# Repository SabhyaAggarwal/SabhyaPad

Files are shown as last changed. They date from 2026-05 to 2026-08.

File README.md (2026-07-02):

# SabhyaPad

This is my own MacroPad, called **SabhyaPad**! It has 6 buttons that can easily be customized using QMK. Using it is really simple: just plug a USB-C cable into your computer, allow it to connect, and then start using it.



I made this so that my life is easier. Currently, it is configured to do this...



## Here is a [video](https://youtu.be/60F119tDTQQ) of it on YouTube!!! I accidentally put the wrong link in the demo section actually...

## BOM
|Item |Quantity|Remarks |Unit Price 1 (INR)|Order Quantity|Order Unit Price (INR)|Order Unit Price (Est. USD)|Link To Buy |
|---|---|---|---|---|---|---|---|
|Switches |6 |Switches of MX style. |₹93.18 |6 |₹93.18 |$1.00 |https://www.mouser.in/ProductDetail/CHERRY/MX1A-L1NN?qs=F5EMLAvA7IDlALNAurZTXA%3D%3D |
|Seeed Studio Xiao RP2040|1 |Main Chip. |₹464.97 |1 |₹464.97 |$4.90 |https://www.mouser.in/ProductDetail/Seeed-Studio/102010630?qs=sqEgtWRSLJ0HHL%252BkmwiGyA%3D%3D |
|Blank DSA keycaps |6 |Blank DSA keycaps of black colour(3d printed).|₹2.13 |6 |₹12.75 |$0.13 |Own 3d printer or print-legion |
|PCB |1 |Main PCB. |₹1112.00 |1 |₹95.25 |$1.00 |allpcb.com |
|M3x16mm screws |4 |Screws. |₹12.27 |4 |₹49.09 |$0.51 |https://robokits.co.in/robot-parts/nut-bolts-standoffs/mushroom-head-bolts/m3-x-16-mm-ss-bolt-precision-stainless-steel-304-moq-25-pcs|
|M3 nuts |4 |Nuts |₹1.18 |4 |₹4.72 |$0.05 |https://robokits.co.in/robot-parts/nut-bolts-standoffs/nuts/m3-nuts-304-stainless-steel-moq-50-pcs |

## Hardware

This is the schematic of my PCB...



And this is what my PCB design looks like...



### 3D Render of PCB



## 3D Models

Please note that I will add USB-C port after I receive the PCB and can confirm the measurements

### Case Render(SabhyaPad Case Assembled)

Screenshot 2026-06-10 at 11 30 27 PM

### Cut Case Render(SabhyaPad Case Cut)

Screenshot 2026-06-10 at 11 31 21 PM

### Final Render(no keycaps)

Screenshot 2026-06-10 at 11 29 30 PM

---

# Assembly

For assembly:
1. 3D Print the case cut file.
2. Take your soldered PCB and push it into the top part. It will click and then it will be attached.
3. Take the bottom part and put it at the bottom.
4. Use M3x16mm screws and the M3 nuts to enclose it.

# Firmware

The SabhyaPad firmware is based on **QMK Firmware** and is located in:

```text
FIRMWARE/sabhyapad
```

## Requirements

Install **QMK MSYS** from:

https://qmk.fm

After installation, open QMK MSYS and verify it is installed correctly:

```bash
qmk --version
```

## Setting Up QMK

Clone and set up QMK Firmware:

```bash
qmk setup
```

## Installing SabhyaPad

Navigate to the keyboards directory:

```bash
cd qmk_firmware/keyboards
```

Clone this repository:

```bash
git clone https://github.com/SabhyaAggarwal/SabhyaPad.git
```

## Building the Firmware

Return to the QMK root directory:

```bash
cd ../..
```

Compile the firmware:

```bash
qmk compile -kb sabhyapad -km default
```

Or:

```bash
make sabhyapad:default
```

## Firmware Output

A successful build will generate:

```text
sabhyapad_default.uf2
```

Since SabhyaPad uses an **RP2040** microcontroller, the firmware is generated in UF2 format.

## Flashing the Firmware

1. Hold the **BOOTSEL** button while plugging the keyboard into your computer.
2. A drive named **RPI-RP2** will appear.
3. Drag and drop:

```text
sabhyapad_default.uf2
```

onto the drive.

The keyboard will automatically reboot and start running the new firmware.

## Updating

Pull the latest changes:

```bash
cd qmk_firmware/keyboards/SabhyaPad
git pull
```

Rebuild:

```bash
cd ../..
qmk compile -kb sabhyapad -km default
```

## Troubleshooting

Check your QMK installation:

```bash
qmk doctor
```

Clean and rebuild:

```bash
qmk clean
qmk compile -kb sabhyapad -km default
```

List available keymaps:

```bash
qmk list-keymaps -kb sabhyapad
```

## Quick Start

```bash
qmk setup

cd qmk_firmware/keyboards
git clone https://github.com/SabhyaAggarwal/SabhyaPad.git

cd ../..

qmk compile -kb sabhyapad -km default
```

### Specifications

- MCU: RP2040
- Switches: 6 Mechanical Switches
- Firmware: QMK
- Connector: USB-C
- Firmware Format: UF2

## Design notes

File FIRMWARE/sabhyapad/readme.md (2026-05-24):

# sabhyapad

sabhyapad

*A short description of the keyboard/project*

* Keyboard Maintainer: [Sabhya Aggarwal](https://github.com/SabhyaAggarwal)
* Hardware Supported: *The PCBs, controllers supported*
* Hardware Availability: *Links to where you can find this hardware*

Make example for this keyboard (after setting up your build environment):

    make sabhyapad:default

Flashing example for this keyboard:

    make sabhyapad:default:flash

See the [build environment setup](https://docs.qmk.fm/#/getting_started_build_tools) and the [make instructions](https://docs.qmk.fm/#/getting_started_make_guide) for more information. Brand new to QMK? Start with our [Complete Newbs Guide](https://docs.qmk.fm/#/newbs).

## Bootloader

Enter the bootloader in 3 ways:

* **Bootmagic reset**: Hold down the key at (0,0) in the matrix (usually the top left key or Escape) and plug in the keyboard
* **Physical reset button**: Briefly press the button on the back of the PCB - some may have pads you must short instead
* **Keycode in layout**: Press the key mapped to `QK_BOOT` if it is available

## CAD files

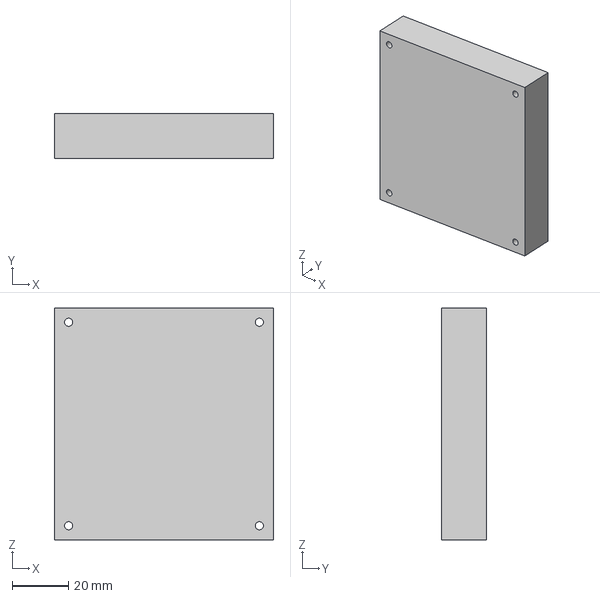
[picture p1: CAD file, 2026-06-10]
CAD/SabhyaPad Case Assembled.step
77.8 x 16.0 x 82.2 mm

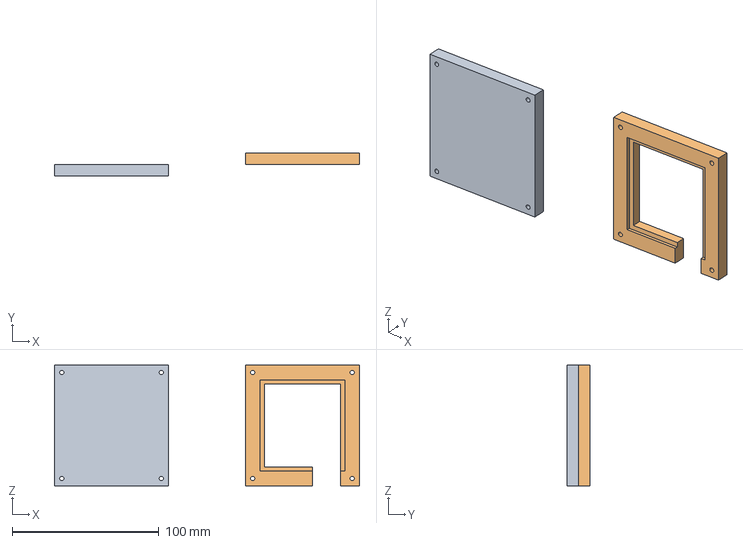
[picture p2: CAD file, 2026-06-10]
CAD/SabhyaPad Case Cut.step
207.8 x 16.0 x 82.2 mm

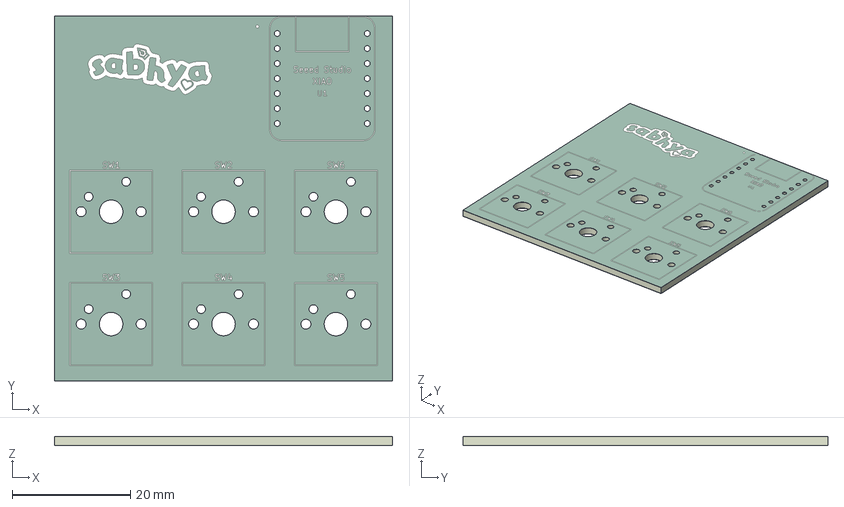
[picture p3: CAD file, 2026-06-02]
PCB/pcb.step
57.3 x 61.8 x 1.64 mm
SabhyaPad_silkscreen
SabhyaPad_soldermask x 2
SabhyaPad_PCB

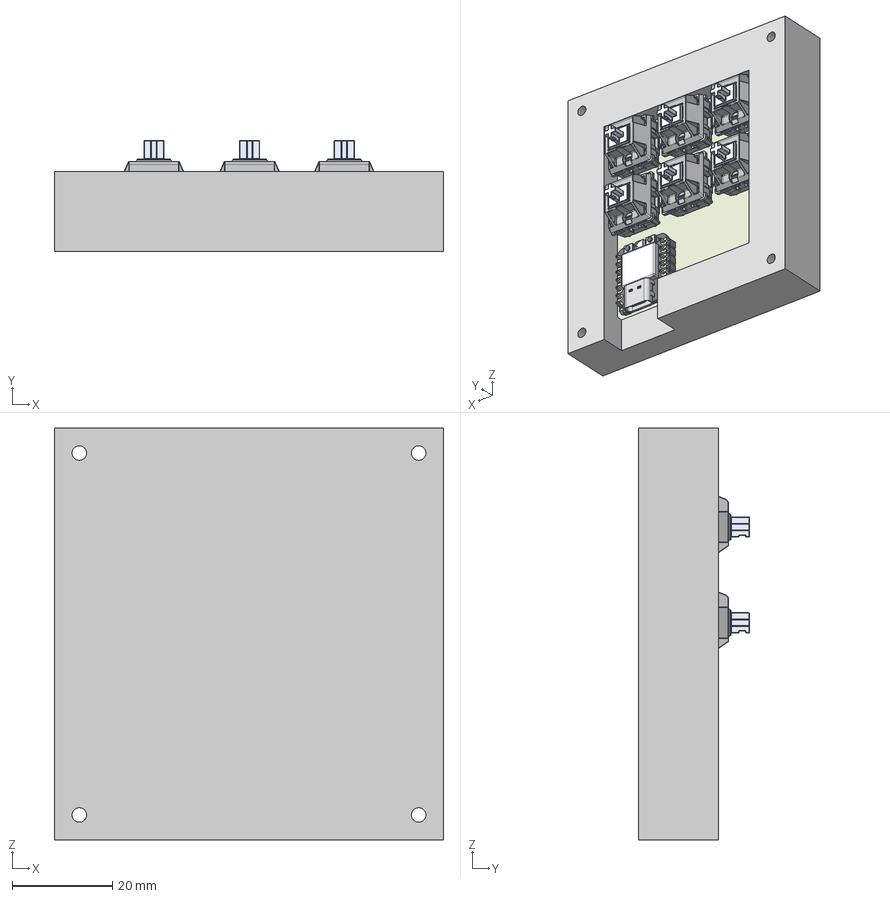
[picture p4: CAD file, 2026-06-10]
CAD/SabhyaPad Case with Components and PCB.step
77.8 x 22.2 x 82.2 mm

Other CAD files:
PRODUCTION/SabhyaPad Case Cut.stl
CAD/SabhyaPad Case Assembled.f3d
CAD/SabhyaPad Case Cut.f3d
CAD/SabhyaPad Case with Components and PCB.f3d
PCB/pcb.stl

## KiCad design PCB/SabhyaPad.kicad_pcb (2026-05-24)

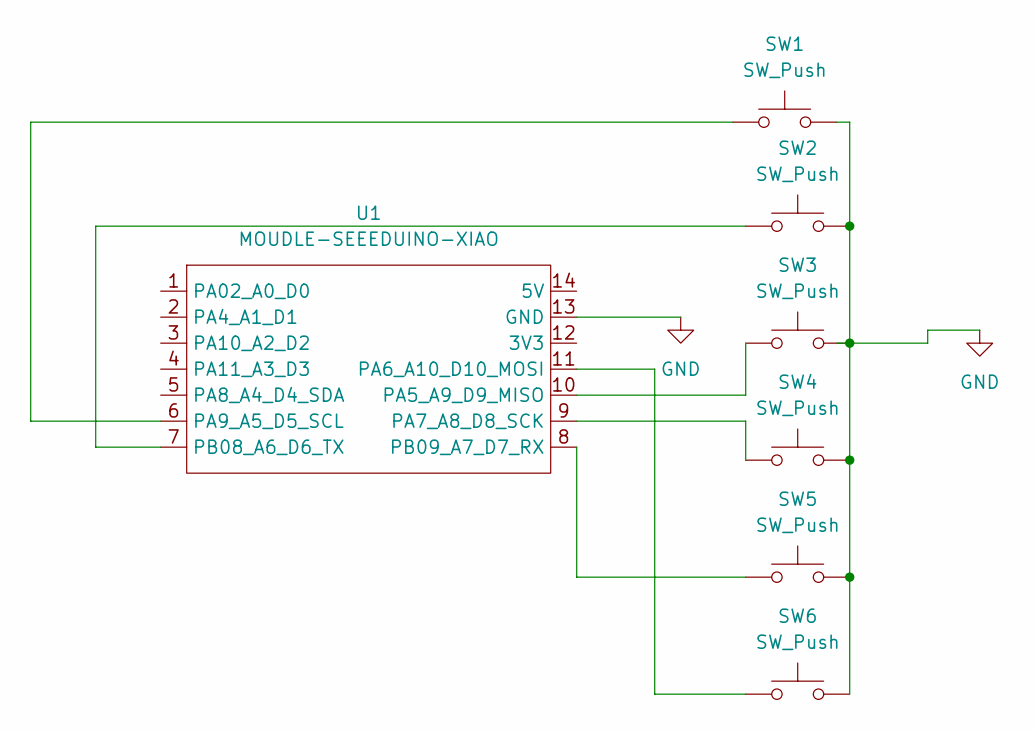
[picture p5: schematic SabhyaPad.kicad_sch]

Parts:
SW1, SW2, SW3, SW4, SW5, SW6: SW_Push; SW_Cherry_MX_1.00u_PCB
U1: MOUDLE-SEEEDUINO-XIAO; XIAO-Generic-Hybrid-14P-2.54-21X17.8MM

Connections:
GND: SW1.2, SW2.2, SW3.2, SW4.2, SW5.2, SW6.2, U1.13 (GND)
unnamed: SW3.1, U1.10 (PA5_A9_D9_MISO)
unnamed: SW6.1, U1.11 (PA6_A10_D10_MOSI)
unnamed: SW4.1, U1.9 (PA7_A8_D8_SCK)
unnamed: SW1.1, U1.6 (PA9_A5_D5_SCL)
unnamed: SW2.1, U1.7 (PB08_A6_D6_TX)
unnamed: SW5.1, U1.8 (PB09_A7_D7_RX)

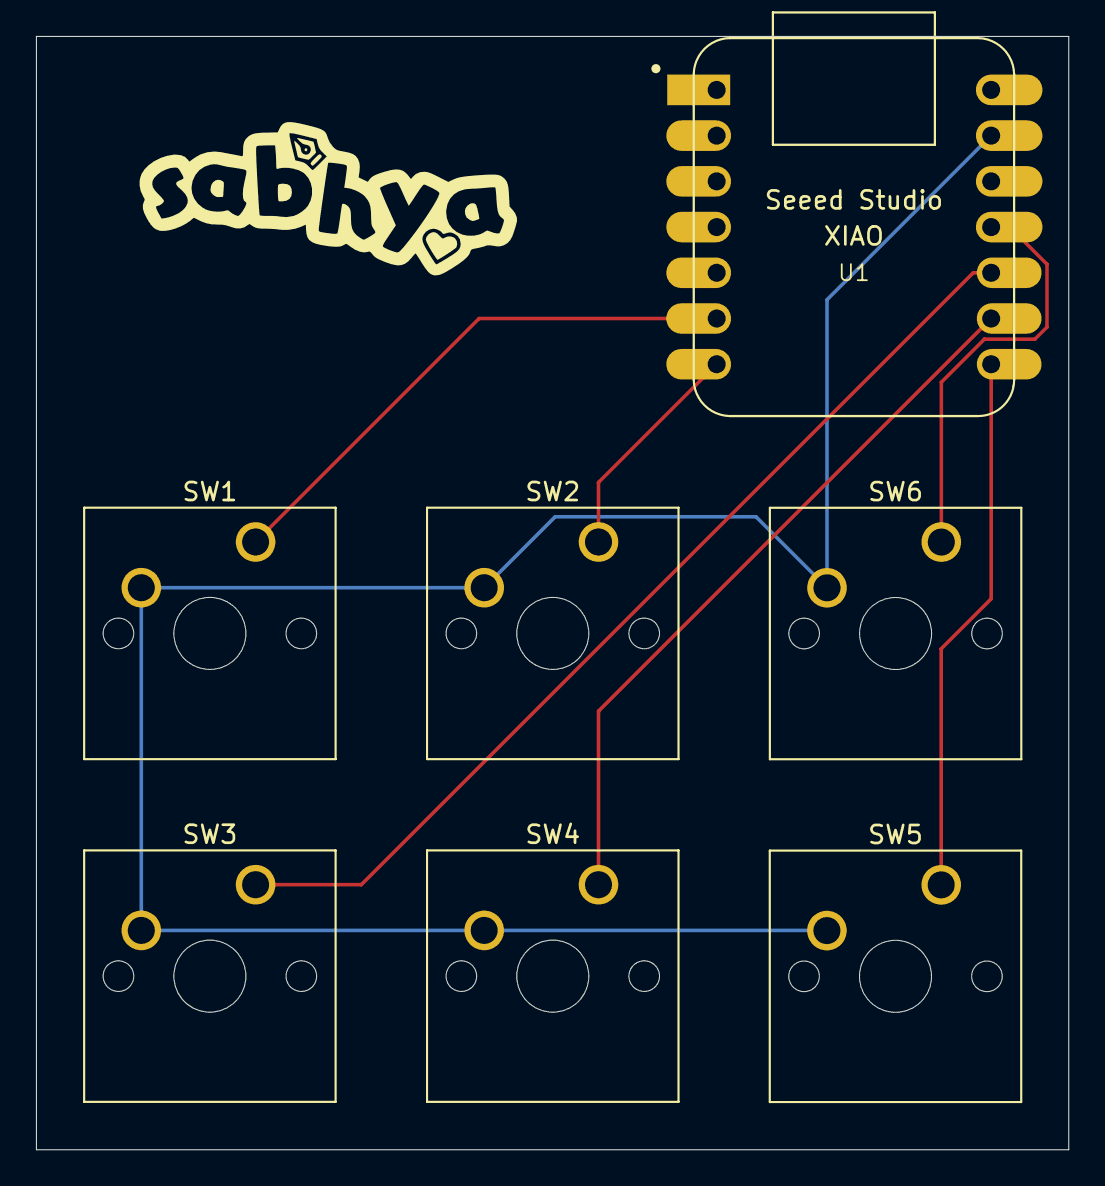
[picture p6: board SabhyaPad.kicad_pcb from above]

Board: 2 copper layers, 57.3 x 61.8 mm, 7 parts (0 on the bottom side), 7 nets.

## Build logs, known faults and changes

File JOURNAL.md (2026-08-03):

---
title: "SabhyaPad"
author: "Sabhya"
description: "A macropad where there are 6 buttons"
created_at: "2026-05-19"
---

# May 19: Main PCB designing

I just designed the schematic for it and made the PCB as well. It would have six keys. A few things I wasn't able to do, like changing the size, but I'll do it today anyway.

It went well. Bro, the time lapse caught me using Slack in the middle of designing.

Main PCB designing

https://cdn.hackclub.com/019e408e-134b-7352-baf1-89e9b5f06e63/image.png

https://cdn.hackclub.com/019e408e-e723-7233-876f-4c35b713b7ee/timelapse.mp4

**Total time spent: 0.6 hours**

# May 19: Deleting my PCB!(accidentally of course)

Hello! Today I made the border then I accidentally deleted my entire PCB and had to remake everything. I also found out that mine had an issue where the footprints were overlapping so it would have been bad but it was still a learning experience. I remade the guide and did everything. I took a little help from Google in understanding things. Otherwise everything went well except for that deletion. If my camera was on you could see the horror on my face. So this is an image of my finalised PCB.

Deleting my PCB

https://cdn.hackclub.com/019e4091-2833-7558-804e-655c1843dd74/image.png

And here's a cool 3d render of it(with ray tracing on)!

Deleting my PCB 3D render

https://cdn.hackclub.com/019e4091-087a-7476-bb34-a088ba1011af/image.png

https://cdn.hackclub.com/019e4091-7744-740d-bf84-8c0a699e2f2b/timelapse.mp4

**Total time spent: 1.4 hours**

# May 19: Case designing(half of it)

I wasn't able to log this yesterday but I had designed some of the case. I wasn't able to complete it

Case designing(half of it)

https://cdn.hackclub.com/019e4092-4de3-79b7-8d2a-9c69851e7665/image.png

https://cdn.hackclub.com/019e4092-e9c8-71b3-8e64-37fd73c047fe/timelapse.mp4

**Total time spent: 0.4 hours**

# May 19: PCB improvement!

I had received feedback on my pcb on slack so decided to take their advice and remade the pcb. DRC kept crashing KiCAD for some reason. Anyways, here's my new and improved PCB-

PCB improvement

https://cdn.hackclub.com/019e4094-3e80-78f4-ae9d-04e17d318857/image.png

https://cdn.hackclub.com/019e4094-d5ae-7170-85f7-19ec9d890bed/timelapse.mp4

**Total time spent: 0.7 hours**

# May 20: Adding the rotary encoder and making more of the case

Today I added a rotary encoder to the PCB and also redesigned case with new dimensions. Designing the case was half of the case I redesigned, so that was not too hard, that was easy. Designing the PCB, I thought I have to align it but I thought I'll just make an unaligned macro pad and if needed I'll align it later anyways. So, here's an image of updated PCB design-

Adding the rotary encoder and making more of the case

https://cdn.hackclub.com/019e45a1-4ebf-7b35-b74a-4d1953734fa8/Screenshot%202026-05-20%20at%203.59.23%E2%80%AFPM.png

And here's a cool ray-traced 3D view of it !

Adding the rotary encoder and making more of the case 3D view

https://cdn.hackclub.com/019e45a1-e363-71c6-a874-f81e0d0e7c70/image.png

https://lapse.hackclub.com/timelapse/UOwvjiEWUxlu

**Total time spent: 1.1 hours**

# May 21: More Case designing

I wasn't able to journal about this yesterday again. I designed more of the case so that there is more. I was not able to understand how to do plates but okay. Here's an image

More Case designing

https://cdn.hackclub.com/019e49e5-296a-7d7a-8cbf-4da7c81a2d14/Screenshot%202026-05-21%20at%203.06.52%E2%80%AFPM.png

https://lapse.hackclub.com/timelapse/VrHDZk4Xr7BD

**Total time spent: 0.5 hours**

# May 21: Struggling in case design...

I started to design the case more. I got the plan to work but I see some gaps so I am going to ask some people whether those gaps matter, etc . here's an image

Struggling in case design

https://cdn.hackclub.com/019e49e6-5411-7848-a51a-91a1a8491f31/Screenshot%202026-05-21%20at%203.08.09%E2%80%AFPM.png

https://lapse.hackclub.com/timelapse/Hs6_qtUfj6Y8

**Total time spent: 0.8 hours**

# May 22: Removing encoder and making it six buttons. Also little bit case design

I realized it's hard to make case so made it 6 buttons. Also fixed case a bit.

Removing encoder and making it six buttons. Also little bit case design

https://cdn.hackclub.com/019e4fd9-41a8-7208-a234-8f3cae6ca49b/Screenshot%202026-05-22%20at%206.51.33%E2%80%AFPM.png

https://lapse.hackclub.com/timelapse/MRdQTWRS1cMO

**Total time spent: 0.4 hours**

# May 22: Redesigned shape of pcb

So I just redesigned the PCB so that it is larger so that it is easier for me to do case designing.

Redesigned shape of pcb

https://cdn.hackclub.com/019e4fda-4252-7451-b697-ae5f150e9016/Screenshot%202026-05-22%20at%206.52.40%E2%80%AFPM.png

https://lapse.hackclub.com/timelapse/P4UqYziHZ559

**Total time spent: 0.75 hours**

# May 23: Silkscreen and routing

Added silkscreen and did routing of the pcb.

Silkscreen and routing

https://cdn.hackclub.com/019e54b6-5d07-78b7-90ce-ea9d67b25806/image.png

Also to the reviewer who is wondering why it took 1.3 hours, I realised that I forgot to put time in my previous two journals. I just added those times to this one to account for it. Please allow this

https://lapse.hackclub.com/timelapse/QUEe5m7jj3fS

**Total time spent: 1.3 hours**

# May 23: Firmware

So I basically just did the firmware and understood how it works and everything.

Firmware

https://cdn.hackclub.com/019e54b8-3d27-7b0a-ad4a-1ee078ad771e/Screenshot%202026-05-23%20at%205.33.36%E2%80%AFPM.png

https://lapse.hackclub.com/timelapse/yPiTl8n6ygpX

**Total time spent: 1.1 hours**

# May 24: Finishing Touches

I made the github repo, compiled the firmware and made a tentative BOM. Here's an image of github repo

Finishing Touches

https://cdn.hackclub.com/019e5b29-92d9-7c19-8863-554d2cee1a48/Screenshot%202026-05-24%20at%2011.35.05%E2%80%AFPM.png

https://lapse.hackclub.com/timelapse/8gDlHhqyUzoS

**Total time spent: 1 hour**

# May 25: Finishing up!

I decided to finish up with my BOM. I know it's an unbelievable amount of time but I'm stupid. Also I forgot to record 1 hr of stuff where I tried to somehow fix 3D printed stuff but to no avail. Went into a rabbit hole about screws in 3d prints but understood absolutely nothing... Alas, my project is now done and dusted! Here's my final finished repo!

Finishing up

https://cdn.hackclub.com/019e6050-250b-7af8-a06d-4d01cbe630e3/screencapture-github-SabhyaAggarwal-SabhyaPad-tree-main-2026-05-25-23_35_04.png

And my readme!

https://lapse.hackclub.com/timelapse/6Sbmm11qsmmi

**Total time spent: 1.8 hours**

# May 26: Somehow fixing my case...

What I did is I somehow in some weird way managed to figure out how the case should look!Realized I was overthinking it!

Somehow fixing my case

https://cdn.hackclub.com/019e6330-7cfd-7e23-be9d-e8e49cc9da46/Screenshot%202026-05-26%20at%2012.59.40%E2%80%AFPM.png

**Total time spent: 1 hour**

# May 26: Finalizing README

I finalised my README with instructions and everything. I made it so that it's now good. Took me a long time though but ok. Here's one final look at my repo...

Finalizing README

https://cdn.hackclub.com/019e6389-e31a-7d31-bac5-edae1a824422/screencapture-github-SabhyaAggarwal-SabhyaPad-tree-main-2026-05-26-14_37_07.png

**Total time spent: 1 hour**

# Jun 2: PCB import!

What I did was try to export my PCB to Fusion 360. After a lot of trial and effort and a lot of googling, I finally somehow got my PCB imported the way I wanted. Went down a rabbit hole. Anyway it was good and bye!

PCB import

https://cdn.hackclub.com/019e8827-bee8-7e36-85f6-4047d0f9bb05/Screenshot%202026-06-02%20at%205.16.02%E2%80%AFPM.png

https://lapse.hackclub.com/timelapse/kiaREY1ZcIGB

**Total time spent: 1.6 hours**

# Jun 2: Final Render!

Hey, today I did the following:
- Imported the switches the Seeed Studio Xiao RP2040.
- Somehow fixed them to the PCB.
- Got the USB-C cutout now.
- Updated all my CAD files so they include the USB-C cutout.
Today was a good day, very happy day. Anyway bye. Here are pics of my final render!

Final Render 1

https://cdn.hackclub.com/019e882b-26d6-7668-a97d-a87eda44285f/Screenshot%202026-06-02%20at%2011.12.01%E2%80%AFAM.png

Final Render 2

https://cdn.hackclub.com/019e882b-62ea-7862-bdb3-1ad9a9c4eec4/Screenshot%202026-06-02%20at%2011.11.56%E2%80%AFAM.png

https://lapse.hackclub.com/timelapse/IfbbeLmuFq54

**Total time spent: 5.8 hours**

# Jun 2: Soldering 1st time experience

So basically, I received my Seeed Studio Xiao RP2040 and I soldered the male header pins on.

Soldering 1st time experience

https://cdn.hackclub.com/019e88d1-0ca1-720c-8a7f-27f2b7bf729a/Screenshot%202026-06-02%20at%208.20.58%E2%80%AFPM.png

https://lapse.hackclub.com/timelapse/fLmklAol_5ux

**Total time spent: 1.6 hours**

# Jun 10: Making it!

I just soldered everything and assembled it. Here is a pic after it's assembled

Making it

https://cdn.hackclub.com/019eb2a1-6b5f-7bcb-b2e6-f31522c88d18/Photo%20on%2010-06-26%20at%2011.12%E2%80%AFPM.jpg

https://lapse.hackclub.com/timelapse/HfvmXoFkX65J

**Total time spent: 1.5 hours**

# Jun 11: Finishing Up!

So I fixed up my readme after fixing up the CAD and I did all that. Basically I fixed the CAD and fixed the Hindi so here's what my final finished GitHub repository looks like -

Finishing Up

https://cdn.hackclub.com/019eb50c-4041-7cb5-b69e-634078fa0cc6/screencapture-github-SabhyaAggarwal-SabhyaPad-tree-main-2026-06-11-10_28_42.png

https://lapse.hackclub.com/timelapse/HbCXGJjwhqoS

**Total time spent: 2 hours**

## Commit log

2026-06-10 Fix CAD
    [SabhyaPad Case Assembled.step, SabhyaPad Case Cut.step, SabhyaPad Case with Components and PCB.step]
2026-06-23 Add Source files and case cut .stl file
    [SabhyaPad Case Assembled.f3d, SabhyaPad Case Cut.f3d, SabhyaPad Case Cut.stl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]
2026-07-03 Add the .stl to prod folder instead of cad folder
    [SabhyaPad Case Cut.stl]
